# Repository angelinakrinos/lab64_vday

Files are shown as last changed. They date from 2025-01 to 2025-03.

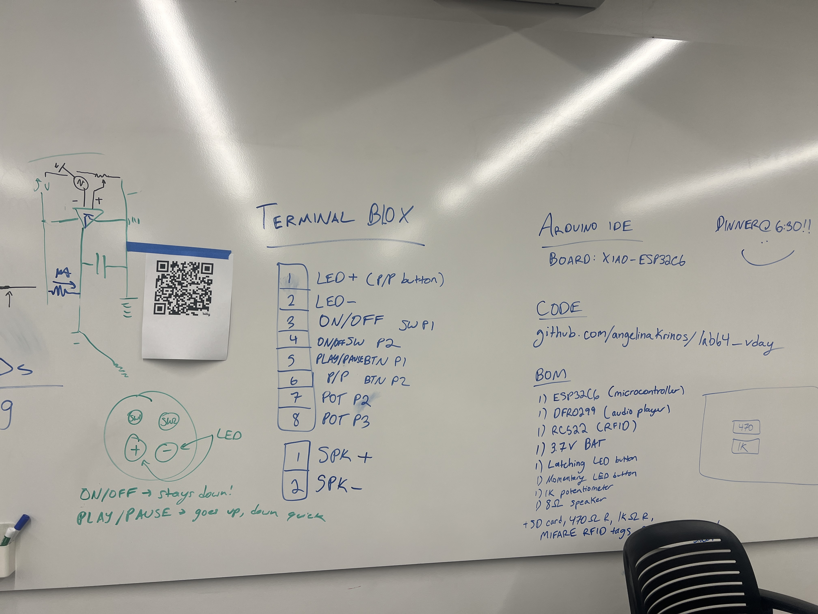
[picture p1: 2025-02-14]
ref_photos/whiteboard_instructions.JPG

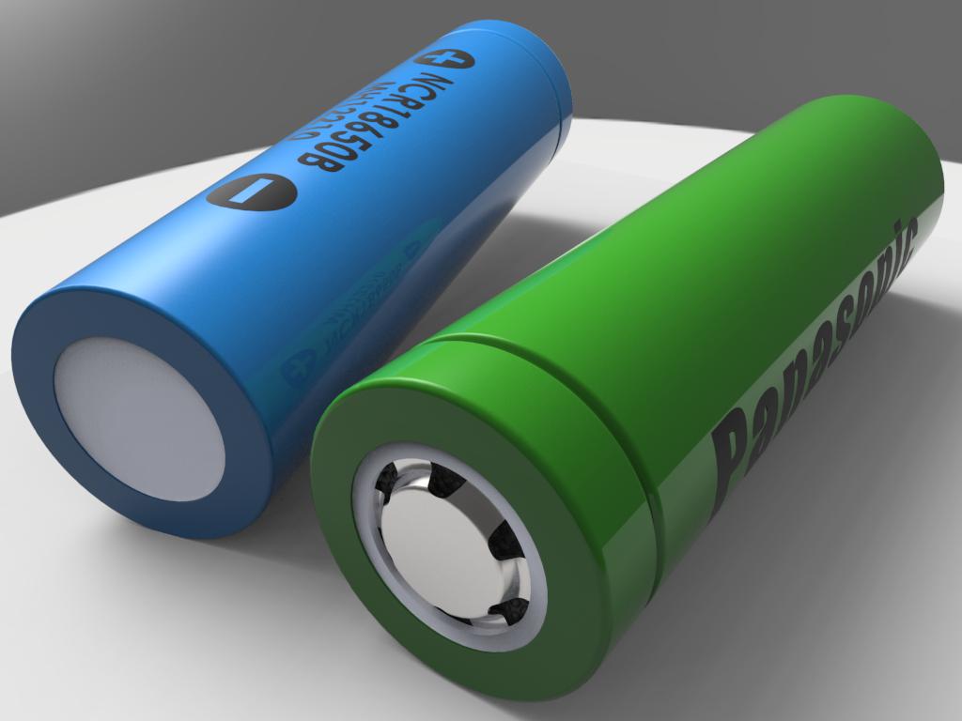
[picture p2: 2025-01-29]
lab64_vday_musicbox/battery-holder-4/Renderings/PANASONIC_NCR-18650B-2.jpg

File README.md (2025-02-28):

# **Lab64 Valentine's Day Music Box 🎵❤️**  
An Arduino-controlled music player for a Lab64 workshop, using an **ESP32C6**, **DFPlayer Mini**, and **RFID module** to create a customizable music box.

## **Workshop Instructions**  

### **Hardware Setup**  
#### 🔧 **Soldering Your Board**  
1. **Microcontroller (XIAO ESP32C6)**  
   - The **battery pads** on the back should be soldered first.  
   - Apply a small amount of solder to the pads before attaching the leads.  
   - Ensure the leads are inserted into the **thru holes** marked **BAT- and BAT+** (they are swapped—**double-check polarity!**).  
   - Solder header pins onto the microcontroller.  

2. **RFID Module**  
   - Solder **longer header pins** into your RFID module for better connection.  

3. **Soldering Components Onto the Board**  
   - **Terminal blocks** should face **outward** so wires can be easily inserted.  
   - The **battery holder** has clearly marked **positive and negative terminals**—pay attention to **snap-in orientation**.  
   - **RFID module** should be soldered as high as possible for better range.  

4. **Connecting Wires**  
   - Terminal blocks will connect to wires, which will connect to your peripherals (speaker, potentiometer, buttons, etc.).  

---

### **Software Setup**  
#### 💻 **Preparing Your Development Environment**  
1. Install **Arduino IDE** (if you haven’t already).  
2. Install the **XIAO ESP32C6 board configuration** in the Arduino IDE.  

#### 🚀 **Uploading the Code**  
- You need to **push the `vday_lab64_workshop_main.ino` code** to your **ESP32C6** for the music box to function.  
- Open `lab64_vday.ino` in Arduino IDE, select the correct **board (ESP32C6)** and **port**, then upload the code.  

#### 📀 **Writing RFID Tags & Playing Music**  
1. **RFID Writing**  
   - Use the provided `rfid_writer.ino` code to write RFID tags.  
   - The writer will **batch-write** tags **sequentially from 1 → ∞** (keep swiping cards to keep writing).  

2. **Music File Setup**  
   - Format your **microSD card to FAT32**.  
   - Inside the SD card, create a folder named **`mp3`**.  
   - Add your MP3 files inside the folder, naming them sequentially:  
     ```
     0001.mp3  
     0002.mp3  
     0003.mp3  
     ...
     ```
   - Insert the **SD card into the DFPlayer Mini** and **swipe an RFID tag** to play its corresponding track.  

---

### **Building the Music Box**  
#### 📦 **Assembling the Enclosure**  
1. Gather all the **box panels**.  
2. **Glue** the sides together using **wood glue**.  
3. **Before attaching the front panel**, install the **back panel** with fasteners—this is where peripherals like:  
   - 🎵 **Speaker**  
   - 🎛️ **Potentiometer**  
   - 🔘 **Buttons**  
   will be mounted.  
4. Customize the **lid** and print it to complete the box!  

🚀 **Enjoy your Valentine's Day Music Box!** 🎶❤️

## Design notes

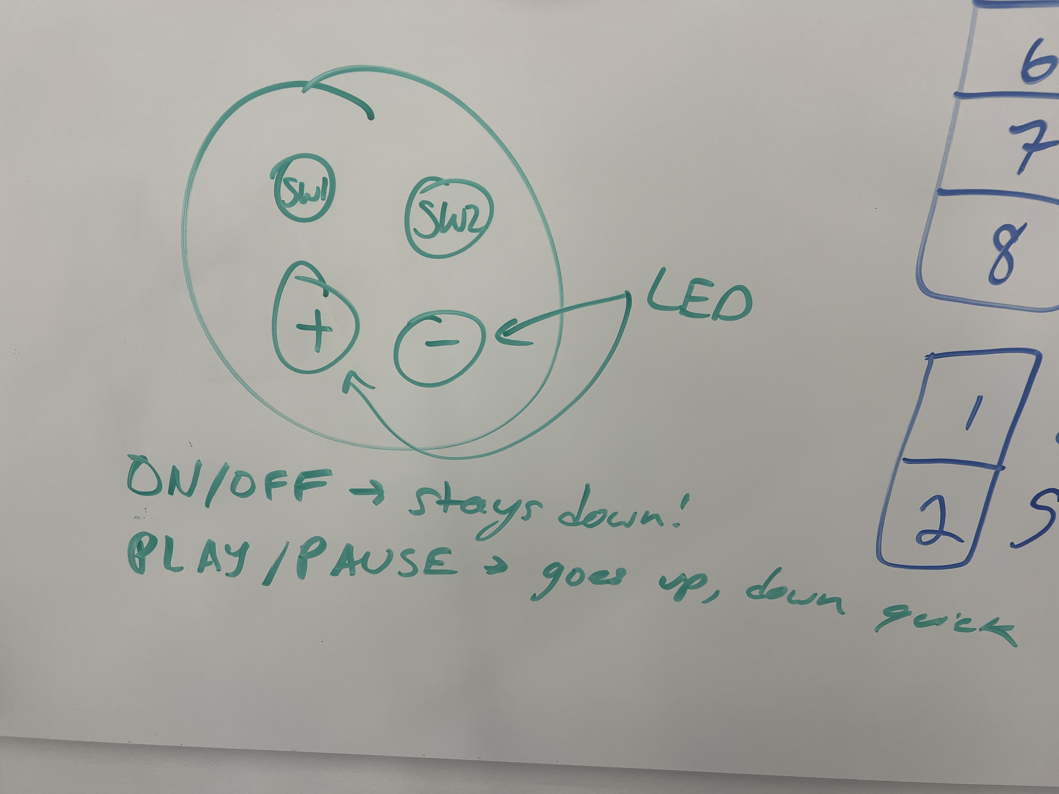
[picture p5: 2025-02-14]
ref_photos/button_pins.JPG

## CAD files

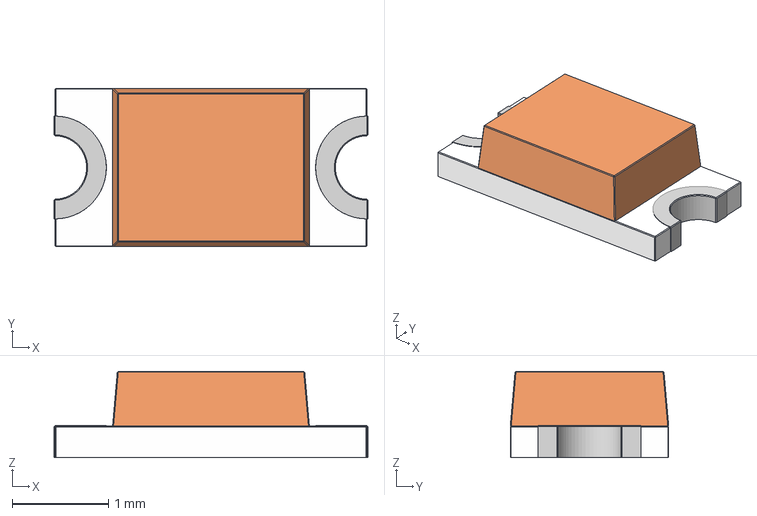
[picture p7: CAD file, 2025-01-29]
lab64_vday_musicbox/1206-smd-led-1/LED_1206_Orange.stp
3.27 x 1.65 x 0.9 mm

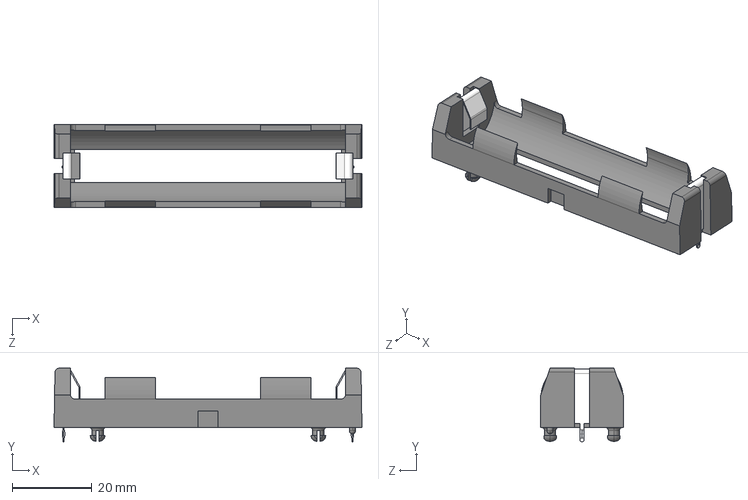
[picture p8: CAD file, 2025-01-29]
lab64_vday_musicbox/BAT_1043/1043.step
77.1 x 18.4 x 20.7 mm

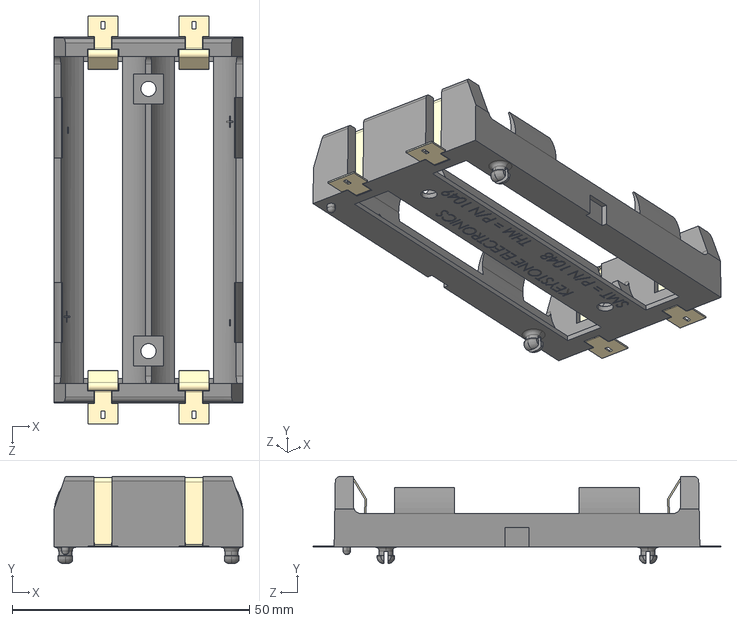
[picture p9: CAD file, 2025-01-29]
lab64_vday_musicbox/BAT_1048/1048.step
39.8 x 18.3 x 86.0 mm

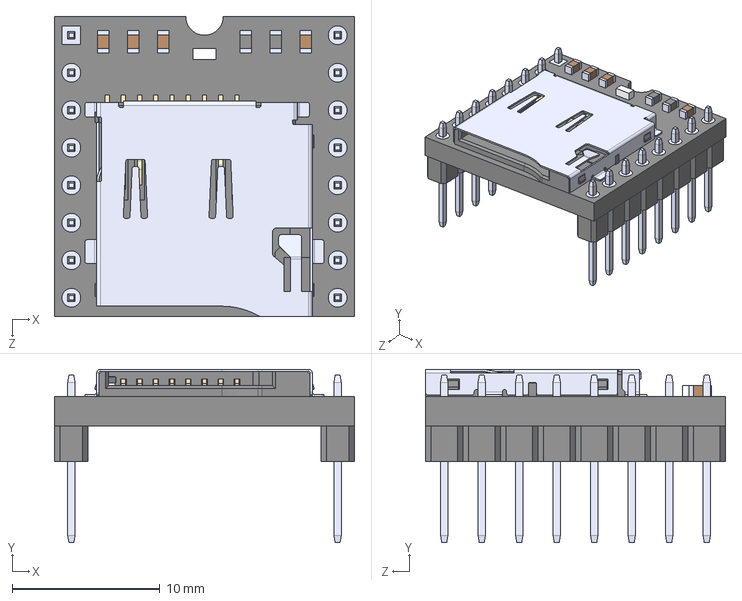
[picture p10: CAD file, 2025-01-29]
lab64_vday_musicbox/DFR0299-cad/DFR0299.step
20.3 x 11.8 x 20.3 mm

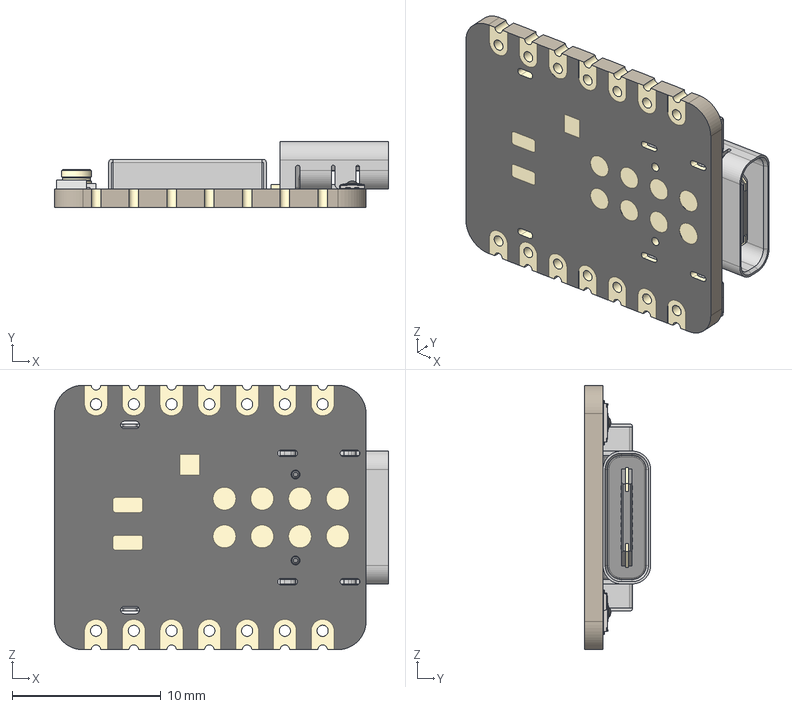
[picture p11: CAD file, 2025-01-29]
lab64_vday_musicbox/seeed-studio-xiao-esp32-c6-1/Seeed Studio XIAO ESP32-C6.step
22.5 x 4.46 x 17.8 mm
BOSS-EXTRUDE14_8_
BOSS-EXTRUDE7_4_
BOSS-EXTRUDE7_3_
BOSS-EXTRUDE14_4_
BOSS-EXTRUDE14_2_
BOSS-EXTRUDE14_11_
BOSS-EXTRUDE7_7_
BOSS-EXTRUDE14_9_
BOSS-EXTRUDE14_3_
BOSS-EXTRUDE14_7_
MIRROR2
BOSS-EXTRUDE14_5_
BOSS-EXTRUDE14_12_
BOSS-EXTRUDE7_8_
BOSS-EXTRUDE7_1_
BOSS-EXTRUDE14_10_
BOSS-EXTRUDE7_9_
BOSS-EXTRUDE14_6_
BOSS-EXTRUDE14_1_
BOSS-EXTRUDE7_6_
BOSS-EXTRUDE7_2_
CUT-EXTRUDE5
BOSS-EXTRUDE7_5_
U.FL Connector v1
Shield
SKTAAAE010 x 2
KH5220-A36 (Ceramic Antenna) v2

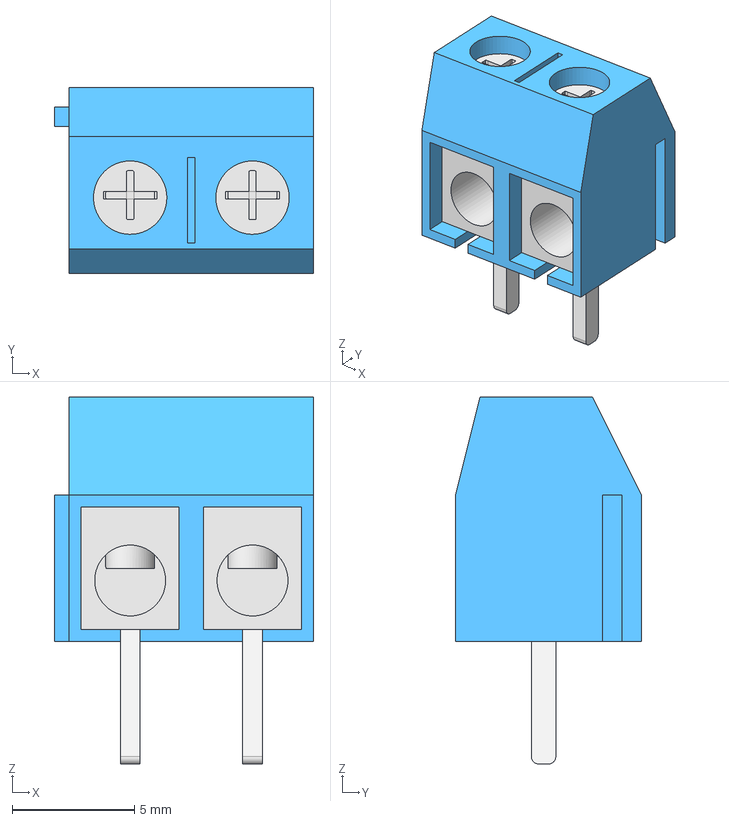
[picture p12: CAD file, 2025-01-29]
lab64_vday_musicbox/terminal-block-2p-5mm-1/Terminal block 5mm.step
10.6 x 7.60 x 15.0 mm
Tornillos001

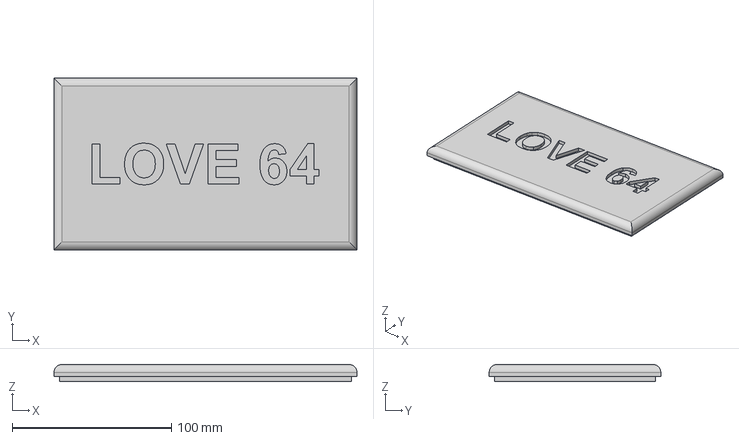
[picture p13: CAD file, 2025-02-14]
structure/CUSTOM_LID/Valentines Lid.step
190.5 x 108.0 x 10.8 mm

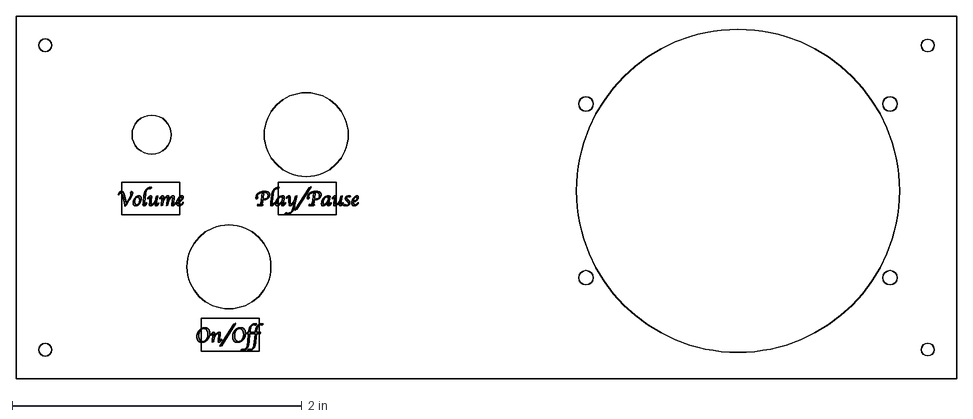
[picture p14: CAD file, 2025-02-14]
structure/Valentines Box v3/back panel v2.dxf
6.49 x 2.50 in

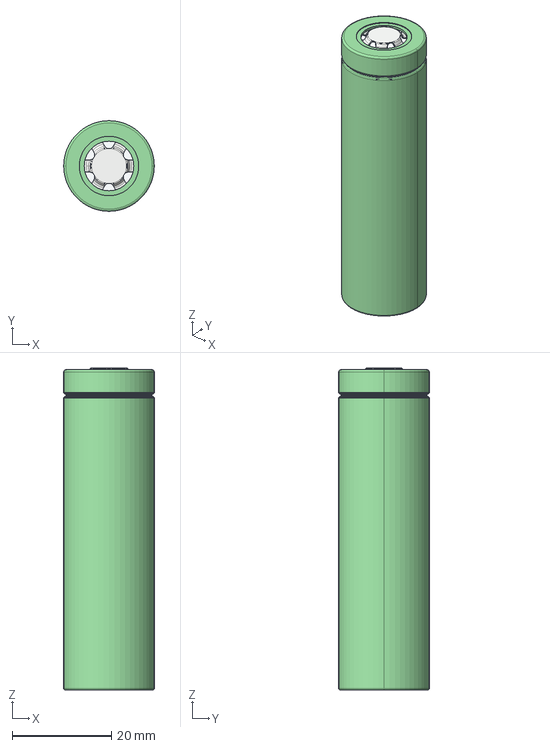
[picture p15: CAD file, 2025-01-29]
lab64_vday_musicbox/battery-holder-4/PANASONIC_NCR-18650B.STEP
18.3 x 18.3 x 65.0 mm

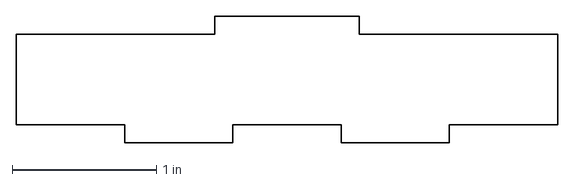
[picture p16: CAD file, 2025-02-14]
structure/Valentines Box v3/support 2.dxf
3.75 x 0.875 in

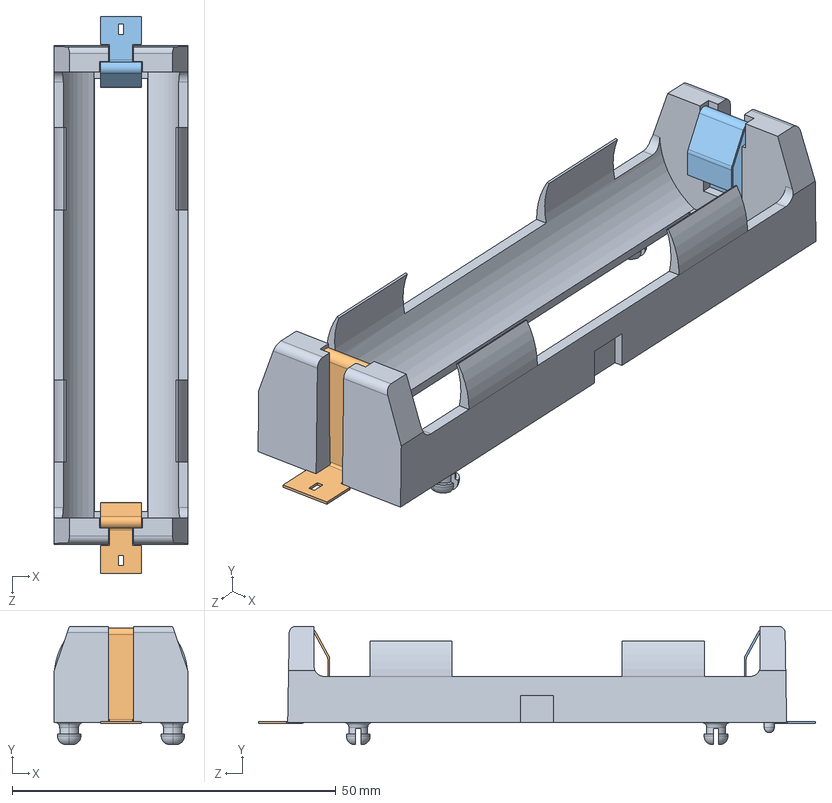
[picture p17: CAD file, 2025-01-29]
lab64_vday_musicbox/battery-holder-4/KEYELCO_1042.STEP
20.7 x 18.3 x 86.0 mm

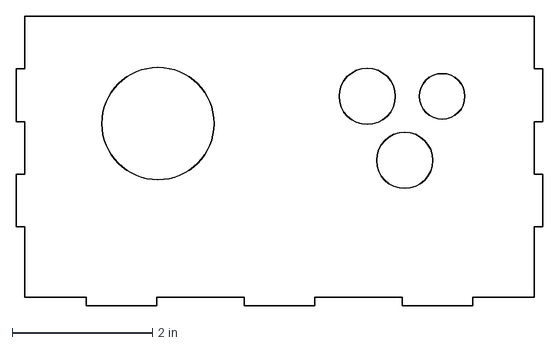
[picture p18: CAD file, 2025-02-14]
structure/Valentines Box v3/back wall v3.dxf
7.50 x 4.12 in

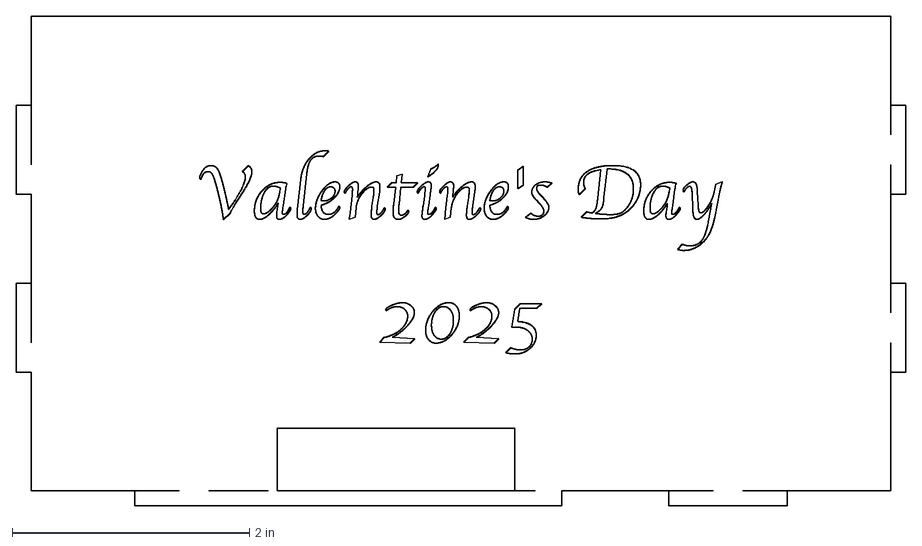
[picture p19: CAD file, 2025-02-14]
structure/Valentines Box v3/front wall v2.dxf
7.50 x 4.12 in

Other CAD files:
lab64_vday_musicbox/battery-holder-4/KEYELCO_1043.STEP
lab64_vday_musicbox/1206-smd-led-1/LED_1206_Green.stp
lab64_vday_musicbox/1206-smd-led-1/LED_1206_Blue.stp
lab64_vday_musicbox/1206-smd-led-1/LED_1206_White.stp
lab64_vday_musicbox/1206-smd-led-1/LED_1206_Red.stp
lab64_vday_musicbox/1206-smd-led-1/LED_1206_Yellow.stp
lab64_vday_musicbox/terminal-block-2p-5mm-1/Terminal block 5mm.stl
structure/CUSTOM_LID/Valentines Lid v0.f3d
structure/Valentines Box v3/Left wall.dxf
structure/Valentines Box v3/Right wall.dxf
structure/Valentines Box v3/bottom.dxf
structure/Valentines Box v3/id card holder.dxf
structure/Valentines Box v3/second floor.dxf
structure/Valentines Box v3/support 1.dxf

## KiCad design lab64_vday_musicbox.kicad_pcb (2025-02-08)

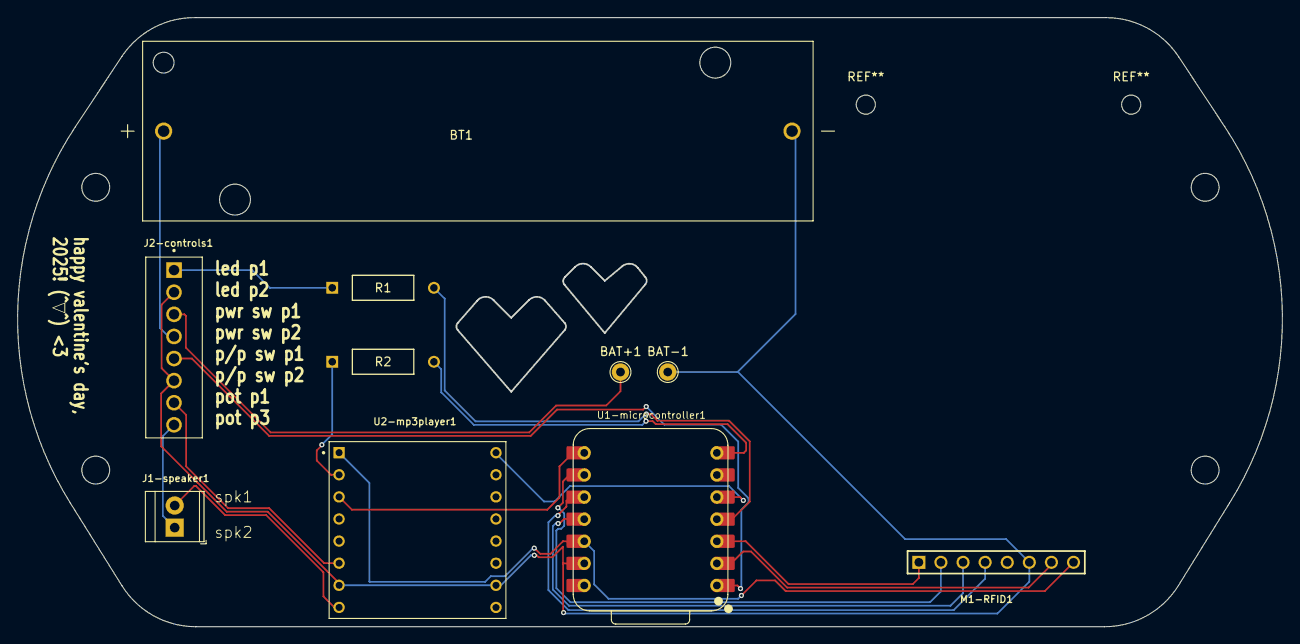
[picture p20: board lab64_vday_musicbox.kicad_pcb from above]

Board: 2 copper layers, 145.4 x 70.0 mm, 10 parts (0 on the bottom side), 19 nets.

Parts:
BAT+1: TestPoint; TestPoint_THTPad_D2.0mm_Drill1.0mm
BAT-1: TestPoint; TestPoint_THTPad_D2.0mm_Drill1.0mm
BT1: 1043; BAT_1043
J1-speaker1: Screw_Terminal_01x02; TerminalBlock_TE_282834-2_1x02_P2.54mm_Horizontal
J2-controls1: Screw_Terminal_01x08; TE_282834-8
M1-RFID1: RFID-RC522
R1: 470; YAG_MF25_YAG
R2: 1K; YAG_MF25_YAG
U1-microcontroller1: XIAO-ESP32-S6-SMD; XIAO-ESP32C6-DIP
U2-mp3player1: DFR0299; MODULE_DFR0299

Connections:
+3.3V: M1-RFID1.8 (3V3), U1-microcontroller1.12 (3V3), U2-mp3player1.1 (VCC)
/GPIO: U1-microcontroller1.5 (GPIO22_D4_SDA), U2-mp3player1.16 (BUSY)
/LED1: J2-controls1.1, R1.1
/MISO: M1-RFID1.4 (MISO), U1-microcontroller1.10 (GPIO20_D9_MISO)
/MOSI: M1-RFID1.3 (MOSI), U1-microcontroller1.11 (GPIO18_D10_MOSI)
/POTP1: J1-speaker1.1, J2-controls1.8
/POTP2: J2-controls1.7, U2-mp3player1.6 (SPK1)
/RST: M1-RFID1.7 (RST), U1-microcontroller1.2 (GPIO1_A1_D1)
/RX_to_TX: U1-microcontroller1.8 (GPIO17_D7_RX), U2-mp3player1.3 (TX)
/SCK: M1-RFID1.2 (SCK), U1-microcontroller1.9 (GPIO19_D8_SCK)
/SS: M1-RFID1.1 (SDA), U1-microcontroller1.3 (GPIO2_A2_D2)
/SW1P1: BAT+1.1, J2-controls1.3
/SW1P2: BT1.P, J2-controls1.4
/SW2P1: J2-controls1.5, U1-microcontroller1.1 (GPIO0_A0_D0)
/TX_to_RX: R2.2, U1-microcontroller1.7 (GPIO16_D6_TX)
GND: BAT-1.1, BT1.N, J2-controls1.2, J2-controls1.6, M1-RFID1.6 (GND), U1-microcontroller1.13 (GND), U2-mp3player1.7 (GND), U2-mp3player1.10 (GND)
unnamed: J1-speaker1.2, U2-mp3player1.8 (SPK2)
unnamed: R1.2, U1-microcontroller1.4 (GPIO21_D3)
unnamed: R2.1, U2-mp3player1.2 (RX)

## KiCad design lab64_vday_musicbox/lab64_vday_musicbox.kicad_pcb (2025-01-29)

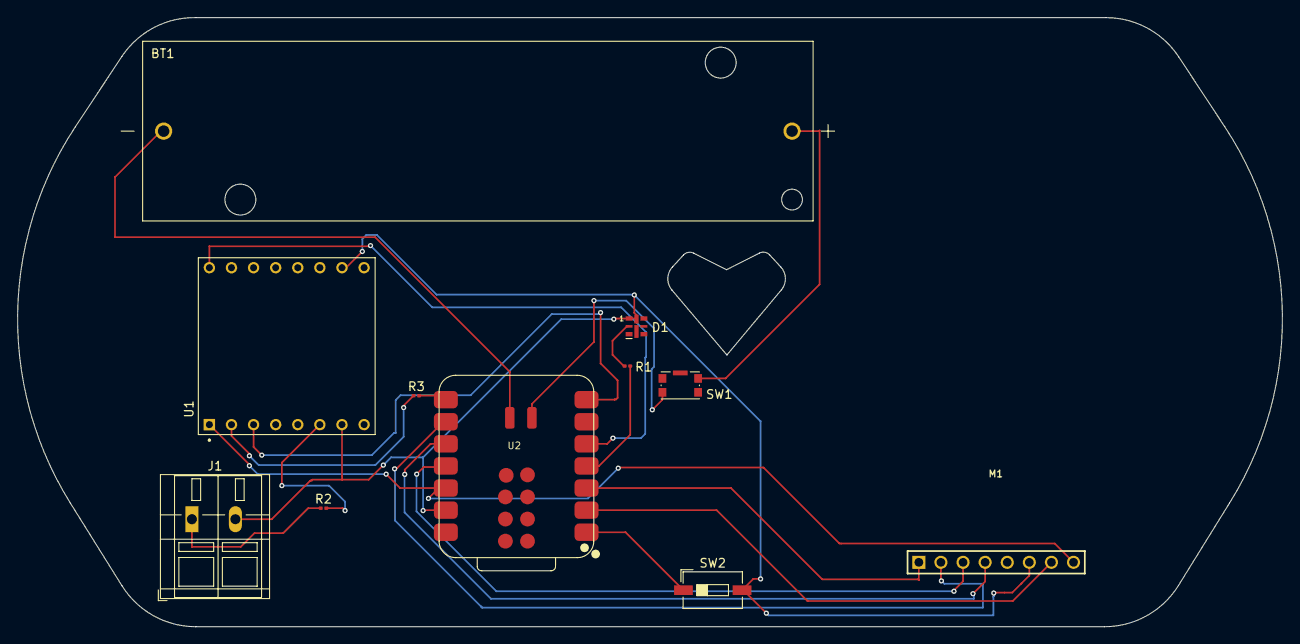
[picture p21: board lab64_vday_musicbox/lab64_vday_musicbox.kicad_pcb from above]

Board: 2 copper layers, 145.4 x 70.0 mm, 11 parts (0 on the bottom side), 19 nets.

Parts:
BT1: 1043; BAT_1043
D1: LED; LED-APA102-2020
J1: Screw_Terminal_01x02; TerminalBlock_WAGO_236-102_1x02_P5.00mm_45Degree
M1: RFID-RC522
R1, R2, R3: R_US; R_0201_0603Metric
SW1: SW_Push; SW_Push_1P1T-SH_NO_CK_KMR2xxG
SW2: SW_SPST; SW_DIP_SPSTx01_Slide_6.7x4.1mm_W6.73mm_P2.54mm_LowProfile_J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
U1: DFR0299; MODULE_DFR0299
U2: XIAO-ESP32-S3-SMD; XIAO-ESP32C6-SMD

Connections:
3.3v: M1.8 (3V3), U1.1 (VCC), U2.12 (3V3)
/GPIO: U1.16 (BUSY), U2.5 (GPIO22_D4_SDA)
/MISO: M1.4 (MISO), U2.10 (GPIO20_D9_MISO)
/MOSI: M1.3 (MOSI), U2.11 (GPIO18_D10_MOSI)
/RST: M1.7 (RST), U2.2 (GPIO1_A1_D1)
/RX: R3.2, U2.8 (GPIO17_D7_RX)
/SCK: M1.2 (SCK), U2.9 (GPIO19_D8_SCK)
/SS: M1.1 (SDA), U2.3 (GPIO2_A2_D2)
/TX: U1.3 (TX), U2.7 (GPIO16_D6_TX)
GND: D1.1 (K), J1.2, M1.6 (GND), SW2.2 (B), U1.7 (GND), U1.10 (GND), U2.13 (GND)
unnamed: BT1.N, U2.16 (GND)
unnamed: BT1.P, SW1.1
unnamed: D1.2 (A), R1.1
unnamed: J1.1, R2.1
unnamed: SW2.1 (A), U2.1 (GPIO0_A0_D0)
unnamed: R3.1, U1.2 (RX)
unnamed: R2.2, U1.6 (SPK1)
unnamed: SW1.2, U2.15 (BAT)
unnamed: R1.2, U2.4 (GPIO21_D3)

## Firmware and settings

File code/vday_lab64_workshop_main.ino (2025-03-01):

/* Lab64 - Valentine's Day Music Box
 * Arduino-controlled music player for a Lab64 workshop
 * Adapted for ESP32C6 by Angelina Krinos
 * Based on work by Turi Scandurra
 * Inspired by Tonuino
 */

#include <Arduino.h>
#include <DFPlayerMini_Fast.h>
#include <HardwareSerial.h>
#include <SPI.h>
#include <MFRC522v2.h>
#include <MFRC522DriverSPI.h>
#include <MFRC522DriverPinSimple.h>
#include <MFRC522Debug.h>

// Pin Definitions for ESP32-C6
#define DFPLAYER_RX 17  // ESP32-C6 RX (DFPlayer TX)
#define DFPLAYER_TX 16  // ESP32-C6 TX (DFPlayer RX)
#define BUSY_PIN 22     // DFPlayer BUSY pin to check playback status
#define BUTTON_PIN 0    // Button for play/pause
#define LED_PIN 21      // LED for status indication

#define SCK_PIN   19    // SPI Clock
#define MISO_PIN  20    // SPI MISO
#define MOSI_PIN  18    // SPI MOSI
#define SS_PIN    2     // MFRC522 SDA (SS)
#define RST_PIN   1     // MFRC522 RST (Optional)

// RFID Initialization
MFRC522DriverPinSimple ss_pin(SS_PIN);
MFRC522DriverSPI driver{ss_pin};
MFRC522 rfid{driver};
MFRC522::MIFARE_Key key;
byte blockAddress = 2;
byte bufferblocksize = 18;
byte blockDataRead[18];

// DFPlayer Mini Initialization
HardwareSerial mySerial(1);
DFPlayerMini_Fast myMP3;

bool isPlaying = false; // Track playback status

void setup() {
  Serial.begin(115200);
  Serial.println("🎵 Initializing Valentine's Day MP3 Player...");

  // DFPlayer Mini setup
  mySerial.begin(9600, SERIAL_8N1, DFPLAYER_RX, DFPLAYER_TX);
  if (!myMP3.begin(mySerial, true)) {
    Serial.println("❌ DFPlayer initialization failed! Check wiring.");
    return;
  }
  Serial.println("✅ DFPlayer Initialized!");
  
  delay(2000); // Allow time for DFPlayer to detect SD card

  pinMode(BUSY_PIN, INPUT);
  pinMode(BUTTON_PIN, INPUT_PULLUP);
  pinMode(LED_PIN, OUTPUT);

  // SPI and RFID setup
  SPI.begin(SCK_PIN, MISO_PIN, MOSI_PIN, SS_PIN);
  rfid.PCD_Init();
  Serial.println(F("✅ RFID Reader Initialized. Ready to scan tags!"));

  // Default authentication key for MIFARE Classic
  for (byte i = 0; i < 6; i++) {
    key.keyByte[i] = 0xFF;
  }
}

void readRFIDTag() {
    if (!rfid.PICC_IsNewCardPresent() || !rfid.PICC_ReadCardSerial()) return;

    Serial.print("📡 Card UID: ");
    MFRC522Debug::PrintUID(Serial, (rfid.uid));
    Serial.println();

    if (rfid.PCD_Authenticate(0x60, blockAddress, &key, &(rfid.uid)) != 0) {
        Serial.println("❌ Authentication failed.");
        return;
    }

    if (rfid.MIFARE_Read(blockAddress, blockDataRead, &bufferblocksize) != 0) {
        Serial.println("❌ Read failed.");
        return;
    }

    // Print raw block data for debugging
    Serial.print("🔍 Raw Block Data: ");
    for (byte i = 0; i < 16; i++) {
        Serial.print(blockDataRead[i], HEX);
        Serial.print(" ");
    }
    Serial.println();

    // Ensure the block is null-terminated
    blockDataRead[15] = '\0';

    Serial.print("🔍 Interpreted as ASCII: ");
    Serial.println((char*)blockDataRead);

    // Extract numeric portion (assumes format "Track XXXX")
    char trackNumStr[5];  // Buffer for "XXXX" + null terminator
    memcpy(trackNumStr, &blockDataRead[6], 4); // Copy only digits
    trackNumStr[4] = '\0'; // Ensure null termination

    int trackNumber = atoi(trackNumStr);
    Serial.print("🎶 Extracted Track Number: ");
    Serial.println(trackNumber);

    if (trackNumber <= 0 || trackNumber > myMP3.numSdTracks()) {
        Serial.println("❌ Invalid track number.");
        return;
    }

    playTrack(trackNumber);
    rfid.PICC_HaltA();
    rfid.PCD_StopCrypto1();  // Allow further card reads
    delay(200);
}


void playTrack(int track) {
  Serial.print("▶️ Playing track: ");
  Serial.println(track);
  myMP3.playFromMP3Folder(track);
  isPlaying = true;
  digitalWrite(LED_PIN, HIGH); // Turn LED on while playing
}

void checkButton() {
  if (digitalRead(BUTTON_PIN) == LOW) {
    delay(200); // Debounce
    if (isPlaying) {
      Serial.println("⏸️ Pausing playback...");
      myMP3.pause();
      isPlaying = false;
      digitalWrite(LED_PIN, LOW);
    } else {
      Serial.println("▶️ Resuming playback...");
      myMP3.resume();
      isPlaying = true;
      digitalWrite(LED_PIN, HIGH);
    }
  }
}

void checkPlaybackStatus() {
  if (digitalRead(BUSY_PIN) == HIGH && isPlaying) {
    Serial.println("⏹️ Playback finished.");
    isPlaying = false;
    digitalWrite(LED_PIN, LOW);
  }
}

void loop() {
  readRFIDTag();
  checkButton();
  checkPlaybackStatus();
  delay(200);
}

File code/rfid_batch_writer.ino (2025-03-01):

/* ESP32C6-based Batch Card Writer for Grimmboy - Arduino-controlled kids' audio player
 * Adapted by Angelina Krinos for Stanford Lab64 Valentine's Day Workshop.
 * Inspired by Turi Scandurra's repo.
 *
 * This code writes sequential track numbers onto MIFARE Classic tags using MFRC522v2.
 */

#include <SPI.h>
#include <MFRC522v2.h>
#include <MFRC522DriverSPI.h>
#include <MFRC522DriverPinSimple.h>
#include <MFRC522Debug.h>

// Pin definitions for ESP32C6
#define SCK_PIN   19  // SPI Clock
#define MISO_PIN  20  // SPI MISO
#define MOSI_PIN  18  // SPI MOSI
#define SS_PIN    2   // MFRC522 SDA (SS)
#define RST_PIN   1   // MFRC522 RST (Optional)

MFRC522DriverPinSimple ss_pin(SS_PIN);
MFRC522DriverSPI driver{ss_pin}; // Create SPI driver
MFRC522 rfid{driver}; // Create MFRC522 instance

MFRC522::MIFARE_Key key;
byte blockAddress = 2;
byte newBlockData[16] = {"Track 0001"}; // Default track number
byte bufferblocksize = 18;
byte blockDataRead[18];
uint16_t currentNumber = 1; // Start track number

void setup() {
  Serial.begin(9600);
  SPI.begin(SCK_PIN, MISO_PIN, MOSI_PIN, SS_PIN);
  rfid.PCD_Init();
  Serial.println(F("RFID Writer Initialized. Warning: This will overwrite data on your card!"));
  
  for (byte i = 0; i < 6; i++) {
    key.keyByte[i] = 0xFF;
  }
}

void loop() {
  if (!rfid.PICC_IsNewCardPresent() || !rfid.PICC_ReadCardSerial()) {
    delay(500);
    return;
  }

  Serial.print("Card UID: ");
  MFRC522Debug::PrintUID(Serial, (rfid.uid));
  Serial.println();

  if (rfid.PCD_Authenticate(0x60, blockAddress, &key, &(rfid.uid)) != 0) {
    Serial.println("Authentication failed.");
    return;
  }

  // Convert track number to ASCII
  sprintf((char*)newBlockData, "Track %04d", currentNumber);
  
  if (rfid.MIFARE_Write(blockAddress, newBlockData, 16) != 0) {
    Serial.println("Write failed.");
  } else {
    Serial.print("Data written successfully in block: ");
    Serial.println(blockAddress);
    
    // Verify by reading back the data
    if (rfid.MIFARE_Read(blockAddress, blockDataRead, &bufferblocksize) != 0) {
      Serial.println("Verification read failed.");
    } else {
      Serial.println("Verification read successful!");
      Serial.print("Data in block ");
      Serial.print(blockAddress);
      Serial.print(": ");
      for (byte i = 0; i < 16; i++) {
        Serial.print((char)blockDataRead[i]);
      }
      Serial.println();
    }
  }

  currentNumber++; // Increment track number
  rfid.PICC_HaltA();
  rfid.PCD_StopCrypto1();
  delay(2000);
}
